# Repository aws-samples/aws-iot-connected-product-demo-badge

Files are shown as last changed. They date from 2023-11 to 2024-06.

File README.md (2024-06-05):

# AWS IoT - Connected Product - Demo Badge

## Workshop

The Demo Badge device was built for this hands-on workshop at re:Invent 2023 and future events:

https://catalog.workshops.aws/aws-iot-connected-product-demo-badge

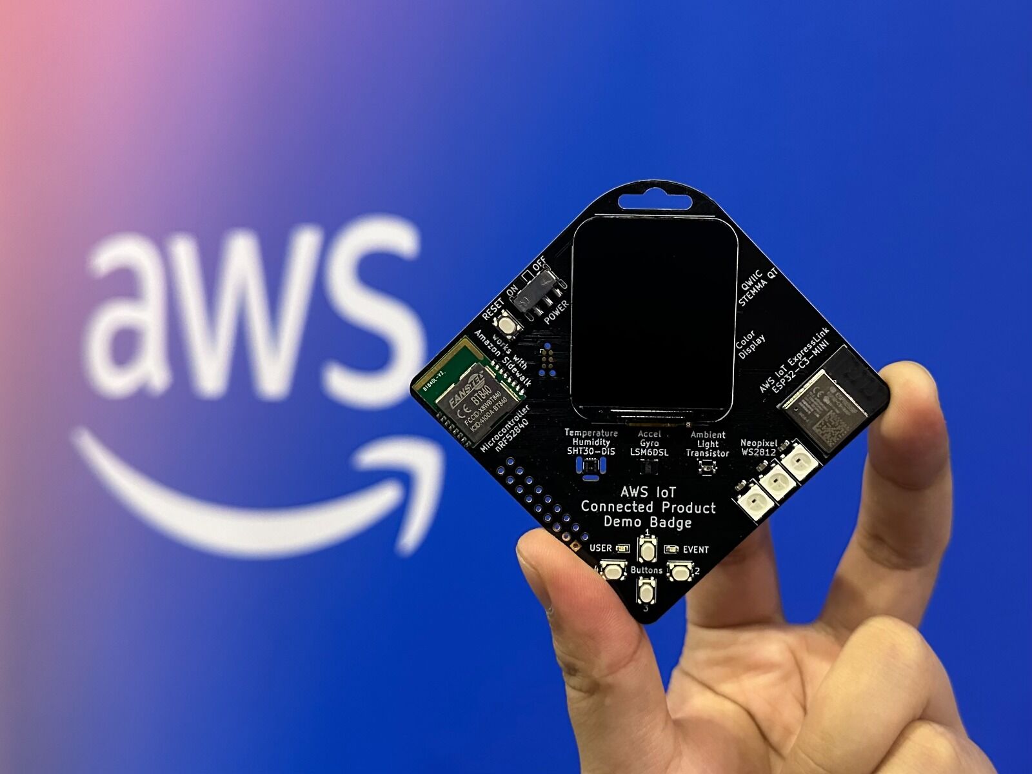
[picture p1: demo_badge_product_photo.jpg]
photo of the Demo Badge


Rendering of front and backside of the Demo Badge:
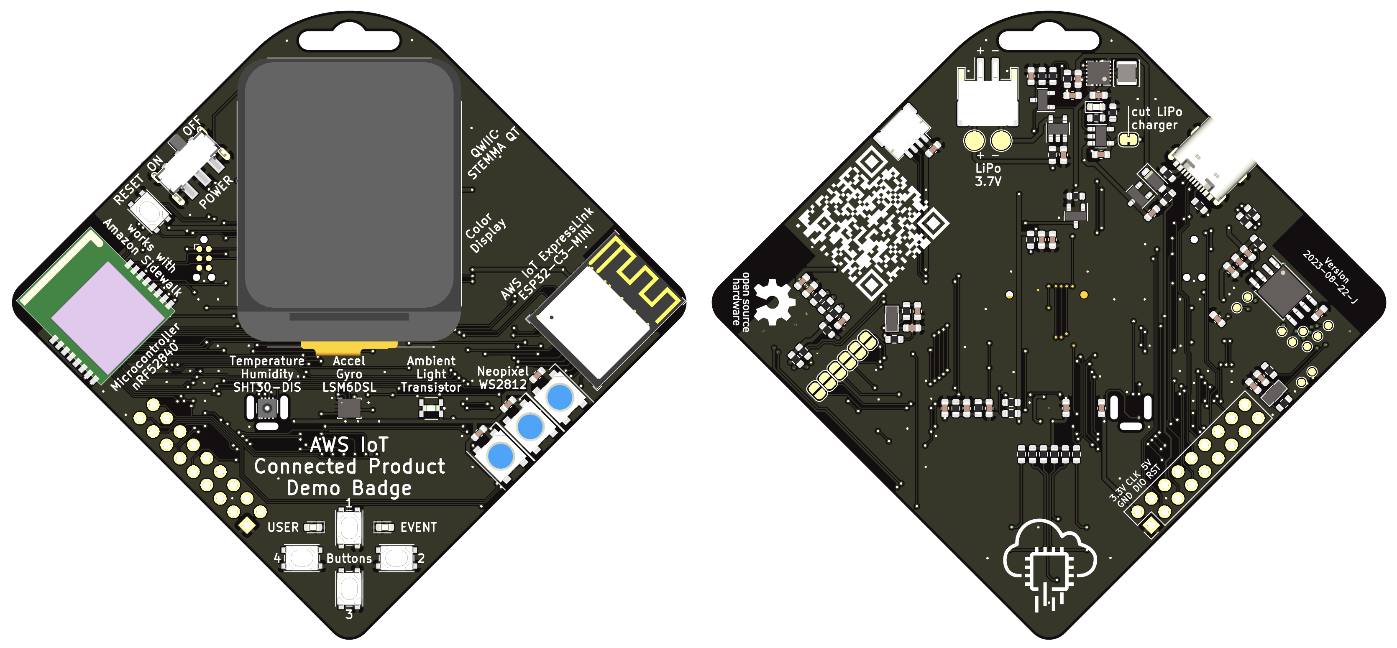
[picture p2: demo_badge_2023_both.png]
rendering of front and backside of Demo Badge


## Hardware

See the [Hardware README](./hardware/README.md) file.

### Where to buy?

Seeed Studio manufactured the devices for re:Invent 2023.

You can pre-order devices directly from the Seeed Studio online store [product listing for the Demo Badge](https://www.seeedstudio.com/AWS-IoT-Connected-Product-p-5844.html).

If you are interesting in customizing the Demo Badge for your own product design, please reach out to fusion@seeed.io directly, and tell them about the Demo Badge device!

## Firmware

See the [Firmware README](./firmware/README.md) file.

## Cloud Infrastructure with CDK

See the [CDK](./cloud-infrastructure/cdk/) folder.

## Security

See [CONTRIBUTING](CONTRIBUTING.md#security-issue-notifications) for more information.

## License

This project is licensed under the MIT-0 License, except files explicitly marked under different license. See the LICENSE file.

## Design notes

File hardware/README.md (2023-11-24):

# AWS IoT - Connected Product - Demo Badge 2023

This device was designed and created for a [hands-on workshop at re:Invent 2023](https://catalog.workshops.aws/aws-iot-connected-product-demo-badge).

The Demo Badge features an nRF52840 microcontroller, an Espressif ESP32-C3-MINI-1-A AWS IoT ExpressLink module, various sensors, buttons, RGB LEDs, and a color display.

## Schematic

The schematic for the Demo Badge is available as KiCAD 7 project. You can access a [PDF version of the schematic here](./snapshot/demo-badge-2023-schematic.pdf).

## PCB Layout

The PCB layout for the Demo Badge is available as KiCAD 7 project, including all footprints (publicly available ones, and custom ones).

You can access the [production Gerber files here](./snapshot/gerbers/).

## License

This hardware design is licensed under the MIT-0 License. Imported footprints and 3D models might contain different licenses.

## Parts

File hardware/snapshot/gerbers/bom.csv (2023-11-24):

LCSC Part # | Designator | Footprint | LCSC Part #
C146233 | A1 | ALS-PT19-315C_L177_TR8 | C146233
C107045 | C29,C34,C39,C40 | C_0603_1608Metric | C107045
C14663 | C1,C2,C3,C10,C14,C18,C20,C22,C41 | C_0603_1608Metric | C14663
C15849 | C4,C5,C6,C11,C15,C17,C21,C35 | C_0603_1608Metric | C15849
C19666 | C8,C30,C31,C36 | C_0603_1608Metric | C19666
C19702 | C7,C19,C28,C32,C33 | C_0603_1608Metric | C19702
C223608 | D7 | D_SOD-123F | C223608
C72043 | D4,D5,D6 | LED_0603_1608Metric | C72043
C2874885 | D1,D2,D3 | SK6812-multi | C2874885
C295747 | J7 | JST_PH_S2B-PH-SM4-TB_1x02-1MP_P2.00mm_Horizontal | C295747
C145956 | J3 | JST_SH_SM04B-SRSS-TB_1x04-1MP_P1.00mm_Horizontal | C145956
C2988369 | J2 | USB_C_Receptacle_Palconn_UTC16-G | C2988369
C167747 | L1 | L_Changjiang_FNR3015S | C167747
C8545 | Q1,Q3 | SOT-23 | C8545
C150470 | Q2 | SOT-23 | C150470
C2999459 | R6 | R_0603_1608Metric | C2999459
C25190 | R3,R4 | R_0603_1608Metric | C25190
C103204 | R16,R17,R34,R49 | R_0603_1608Metric | C103204
C21190 | R8,R33,R52 | R_0603_1608Metric | C21190
C3013567 | R22,R23,R29,R35,R36 | R_0603_1608Metric | C3013567
C25804 | R5,R7,R9,R10,R11,R12,R13,R14,R15,R18,R19,R20,R31,R37,R50 | R_0603_1608Metric | C25804
C103809 | R2 | R_0603_1608Metric | C103809
C163869 | R1 | R_0603_1608Metric | C163869
C221660 | SW8 | JS102011SAQN | C221660
C2689510 | SW1,SW2,SW3,SW4,SW5 | PTS815 | C2689510
C328560 | U12 | SOT-23-5 | C328560
C5182373 | U4 | Fanstel-BT840 | C5182373
C9900056240 | U13 | ER-TFT1.69-2 | C9900056240
C5224444 | U6 | ESP32-C3-MINI-1 | C5224444
C126672 | U5 | LGA-14_3x2.5mm_P0.5mm_LayoutBorder3x4y | C126672
C77361 | U1 | Sensirion_DFN-8-1EP_2.5x2.5mm_P0.5mm_EP1.1x1.7mm | C77361
C668215 | U10 | SOT-23-5 | C668215
C28060 | U9 | Texas_DRC0010J | C28060
C97521 | U14 | SOIC-8_5.23x5.23mm_P1.27mm | C97521
C3035215 | Y1,Y3 | Crystal_SMD_3215-2Pin_3.2x1.5mm | C3035215

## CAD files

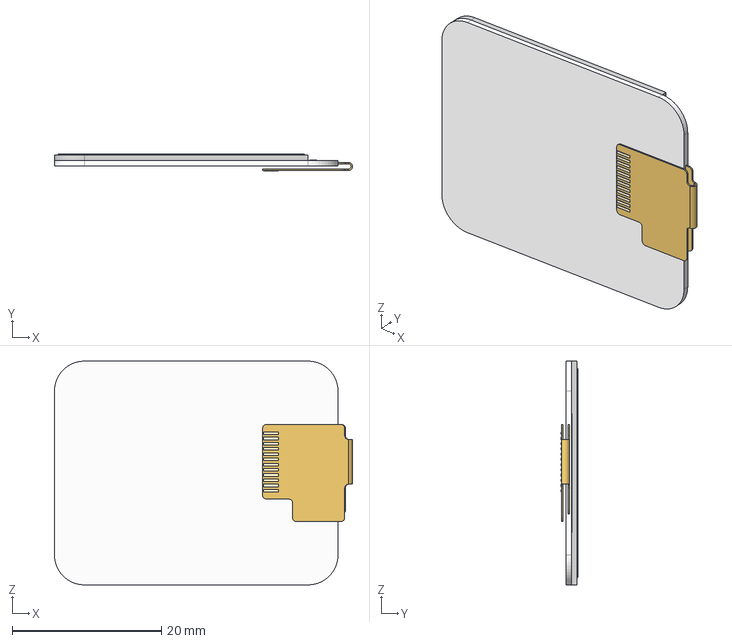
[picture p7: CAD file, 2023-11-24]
hardware/components/1.69” Round IPS.step
39.9 x 2.25 x 30.0 mm

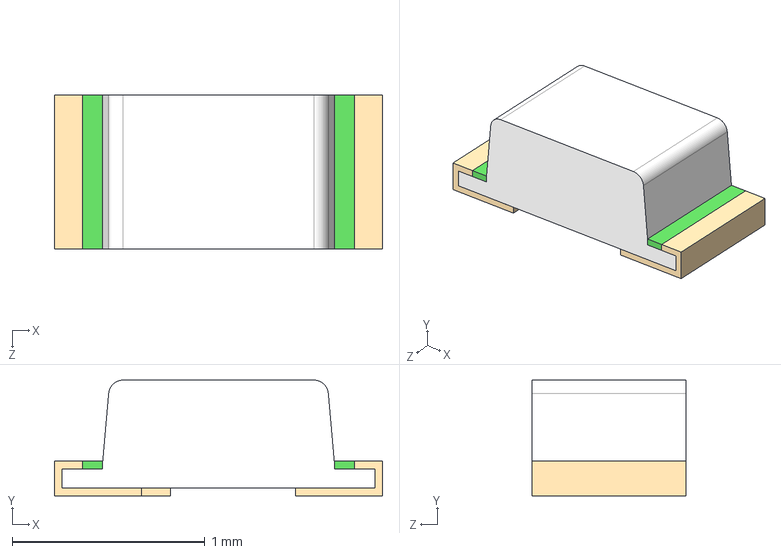
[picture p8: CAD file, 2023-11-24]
hardware/components/ALS-PT19-315C_L177_TR8/ALS-PT19-315C_L177_TR8.step
1.70 x 0.6 x 0.8 mm

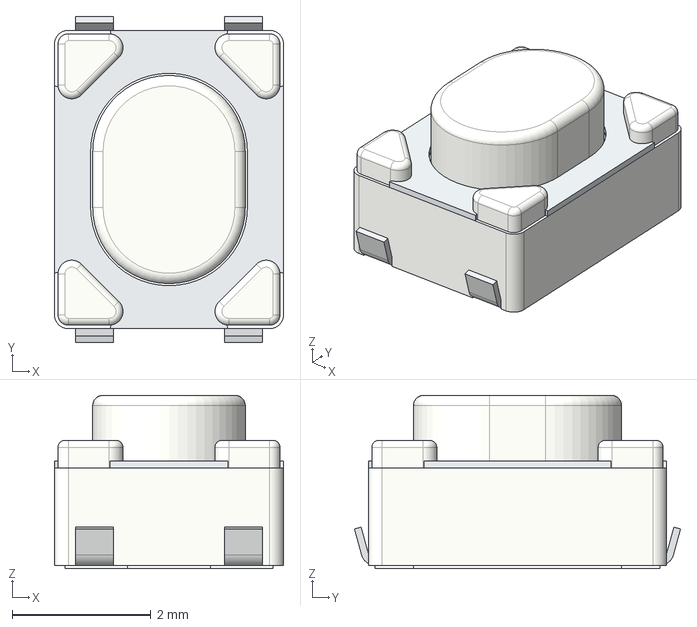
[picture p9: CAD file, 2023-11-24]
hardware/components/PTS815/PTS815.stp
3.30 x 4.70 x 2.50 mm

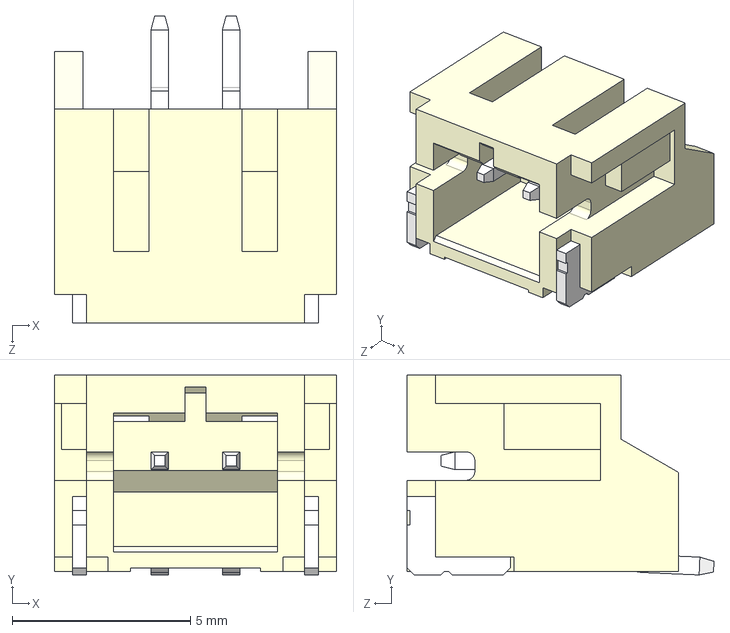
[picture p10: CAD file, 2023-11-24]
hardware/components/S2B-PH-SM4-TB(LF)(SN)--3DModel-STEP-56544.STEP
7.90 x 5.60 x 8.60 mm

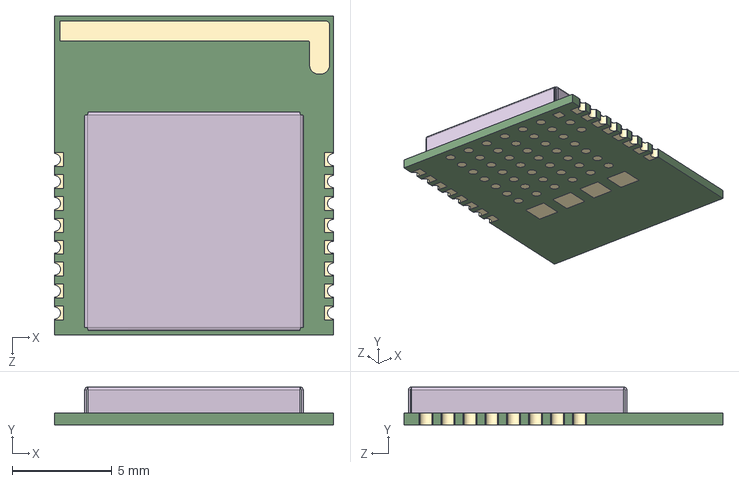
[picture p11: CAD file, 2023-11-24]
hardware/components/BT840.step
14.0 x 1.90 x 16.0 mm

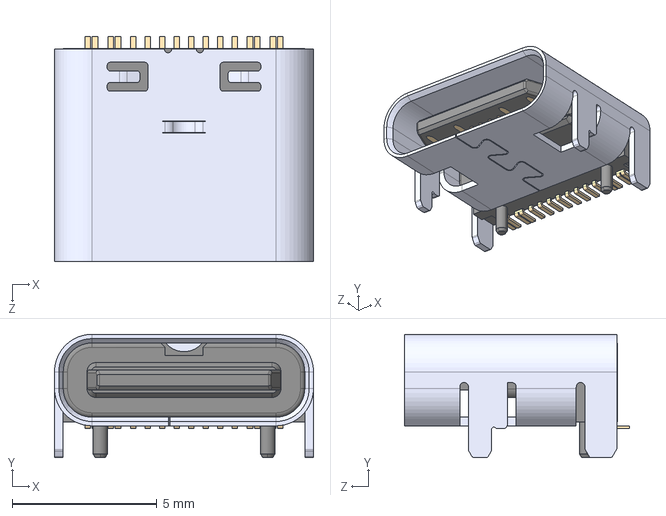
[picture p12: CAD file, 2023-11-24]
hardware/components/CSP-USC16-TR--3DModel-STEP-468060.STEP
8.94 x 4.26 x 7.75 mm

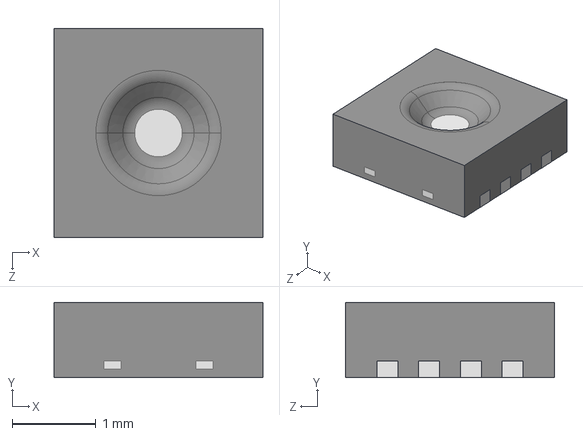
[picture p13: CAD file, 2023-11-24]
hardware/components/SHT30-DIS.STEP
2.50 x 0.901 x 2.50 mm

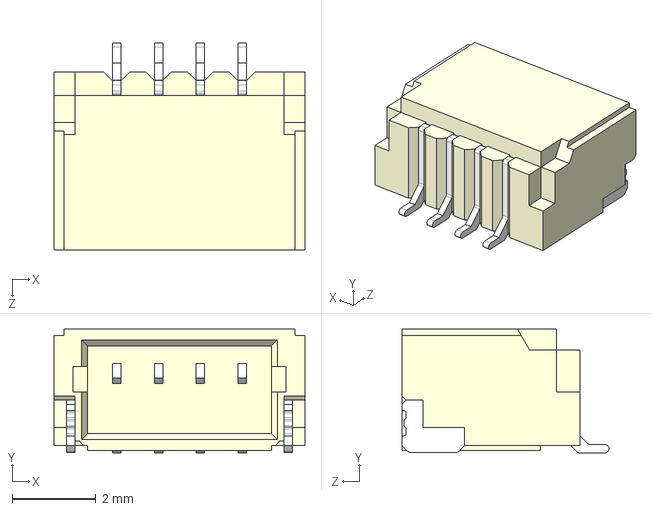
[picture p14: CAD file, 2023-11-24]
hardware/components/SM04B-SRSS-TB.STEP
6.00 x 2.96 x 4.95 mm

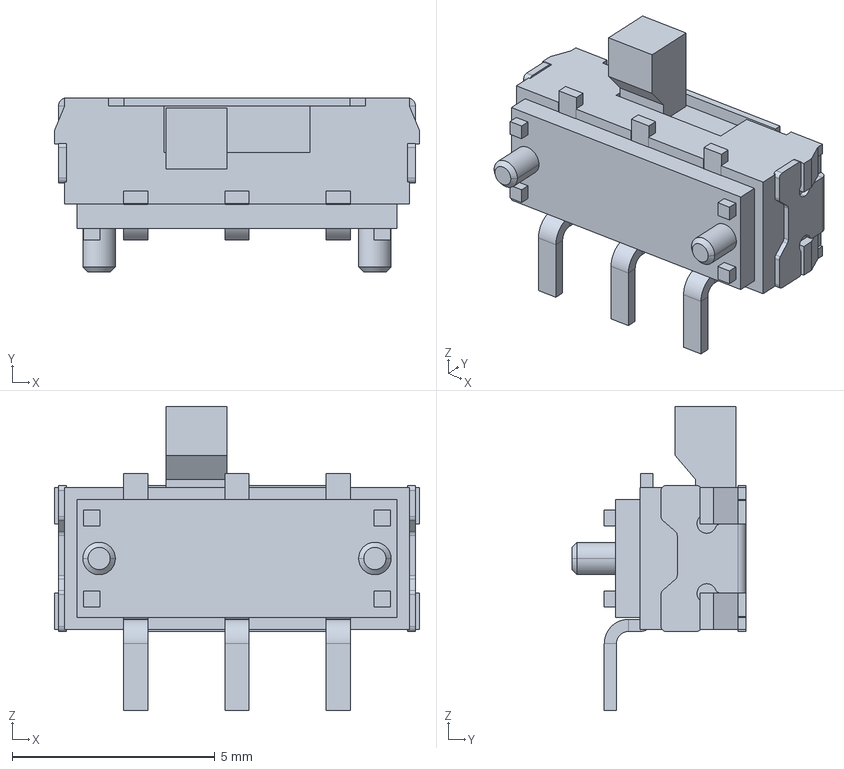
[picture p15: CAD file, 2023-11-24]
hardware/components/JS102011SAQN/JS102011SAQN.step
9.00 x 4.30 x 7.50 mm

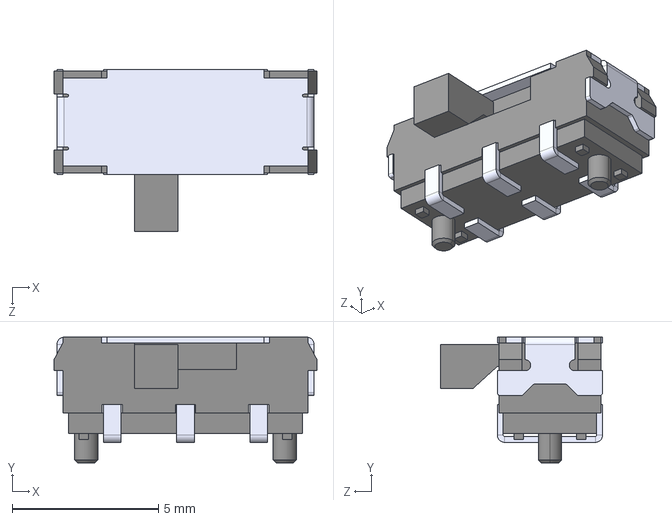
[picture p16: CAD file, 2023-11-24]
hardware/components/JS202011JAQN/JS202011JAQN.step
9.00 x 4.30 x 5.55 mm

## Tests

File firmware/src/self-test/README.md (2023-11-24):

# AWS IoT - Connected Product - Demo Badge 2023

This document will guide you through the steps to:
- flash the Demo Badge device with a self-test FW
- run the self-test FW to perform a functional test of the device

## Setup
- programming tool:
  - linux or windows machine
  - OpenOCD v0.12.0
  - a nrf52 programmer supported by OpenOCD
- the "demobadge-xxx.zip" archive
- device:
  - programmer connected to the programming port
  - USB-C cable connected to the port
  - POWER switch in the ON position

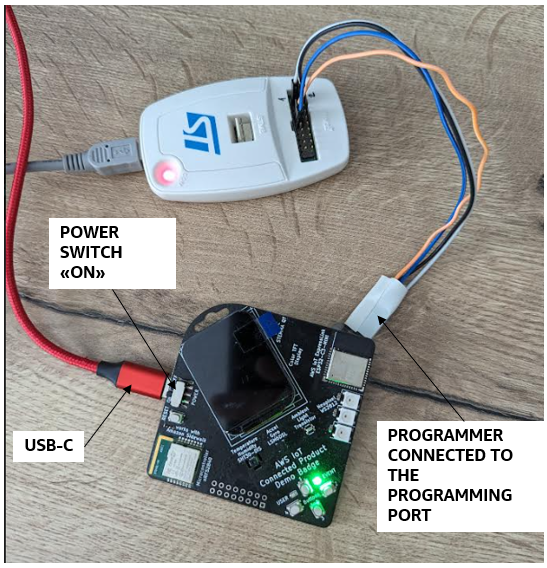
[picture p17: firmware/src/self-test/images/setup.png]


## STEP1. unzip the self-test FW package
Copy the demobadge-xxx.zip archive to the linux/windows machine and unzip it.

On a linux machine:

```bash
unzip demobadge-xxx.zip
```

Make sure the following files has been extracted to folder "./demobadge-xxx"
./flash.cfg
./build/self_test_firmware_20230922.hex

## STEP2. flash the self-test FW
Flash the "self_test_firmware_20230922.hex" to the device.

On a linux machine:

```bash
cd ./demobadge-xxx/
openocd -f flash.cfg
```

If the programming was successful, OpenOCD's output should look like:



## STEP3. run the tests
The device is now programmed with the self-test FW.

### TEST 1
- ACTION:
  - make sure the device is powered on through the USB-C cable
  - make sure the POWER SWITCH is in the ON position
- SUCCESS CRITERIA:
  - all LEDs are OFF
  - display shows "Press B1"
  - display and LEDs must look like this:

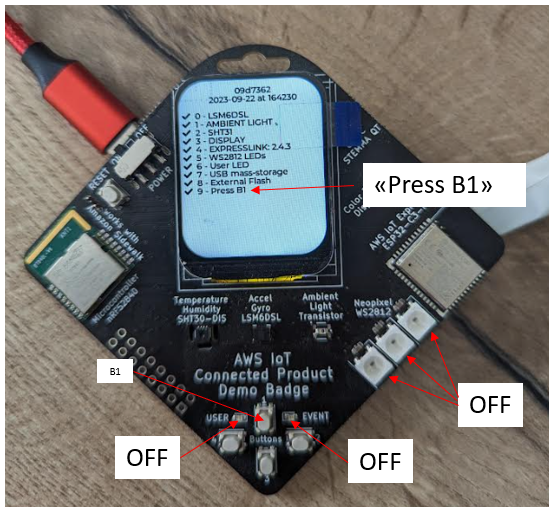
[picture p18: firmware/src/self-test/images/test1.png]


In case the LEDs or the display do not behave as described, press the RESET button and try TEST1 again.

If it does not work, power-cycle the device:
- move the POWER switch to the OFF position
- wait 1s
- move the POWER switch to the ON position
- try TEST1 again

If it fails, discard the device.
Otherwise move to next test.

### TEST 2
- ACTION:
  - do press user button 1
- SUCCESS CRITERIA:
  - strip LED 1 turns on to BLUE
  - display shows "Press B2"
  - display and LEDs must look like this:

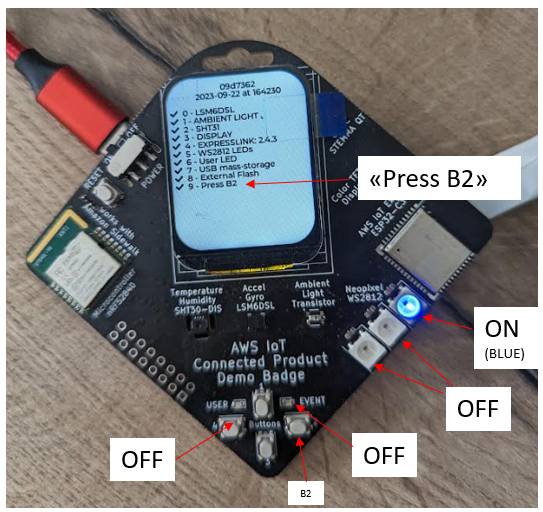
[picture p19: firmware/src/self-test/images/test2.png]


If it fails, discard the device.
Otherwise move to next test.

### TEST 3
- ACTION:
  - do press user button 2
- SUCCESS CRITERIA:
  - strip LED 1 and 2 turn on to BLUE
  - display shows "Press B3"
  - display and LEDs must look like this:

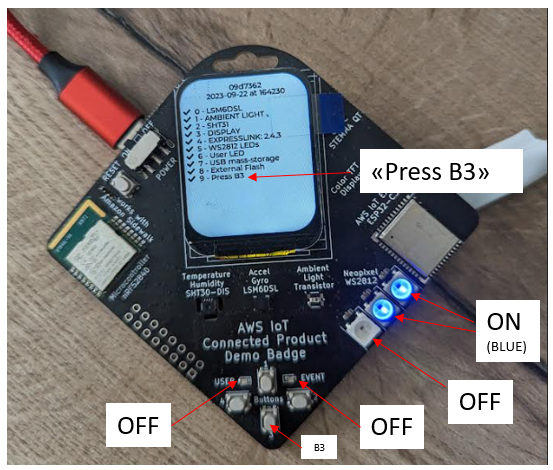
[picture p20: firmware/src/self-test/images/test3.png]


If it fails, discard the device.
Otherwise move to next test.

### TEST 4
- ACTION:
  - do press user button 3
- SUCCESS CRITERIA:
  - strip LED 1, 2, and 3 turn on to BLUE
  - display shows "Press B4"
  - display and LEDs must look like this:

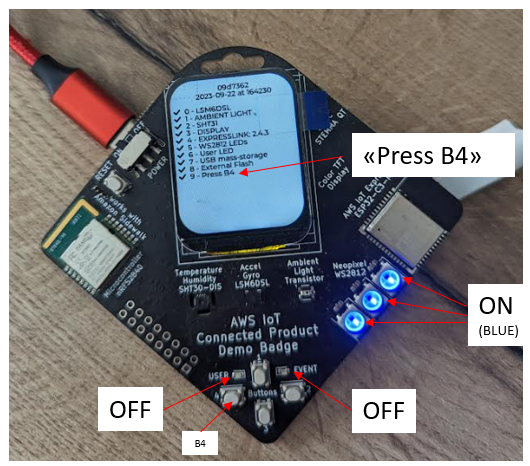
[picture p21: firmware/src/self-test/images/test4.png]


If it fails, discard the device.
Otherwise move to next test.

### TEST 5

- ACTION:
  - press user button 4
- SUCCESS CRITERIA:
  - display shows "PASSED"
  - ALL the LEDs (3xStrip, 1xUSER and 1xEVENT LEDs) are ON and GREEN
  - display and LEDs must look like this:

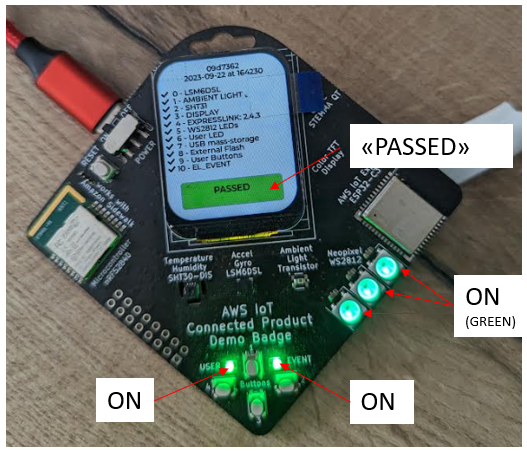
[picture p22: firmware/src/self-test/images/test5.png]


If it fails, discard the device.
Otherwise the self-test has PASSED.

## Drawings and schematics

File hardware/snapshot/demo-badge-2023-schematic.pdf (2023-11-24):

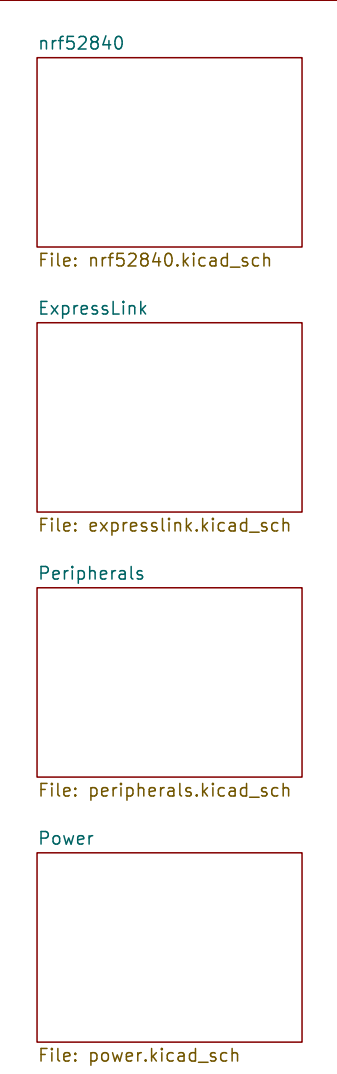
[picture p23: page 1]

nrf52840 File: nrf52840.kicad_sch Power File: power.kicad_sch

https://github.com/aws-samples/aws-iot-connected-product-demo-badge

Id: 1/5 Title: AWS IoT - Connected Product - Demo Badge 2023

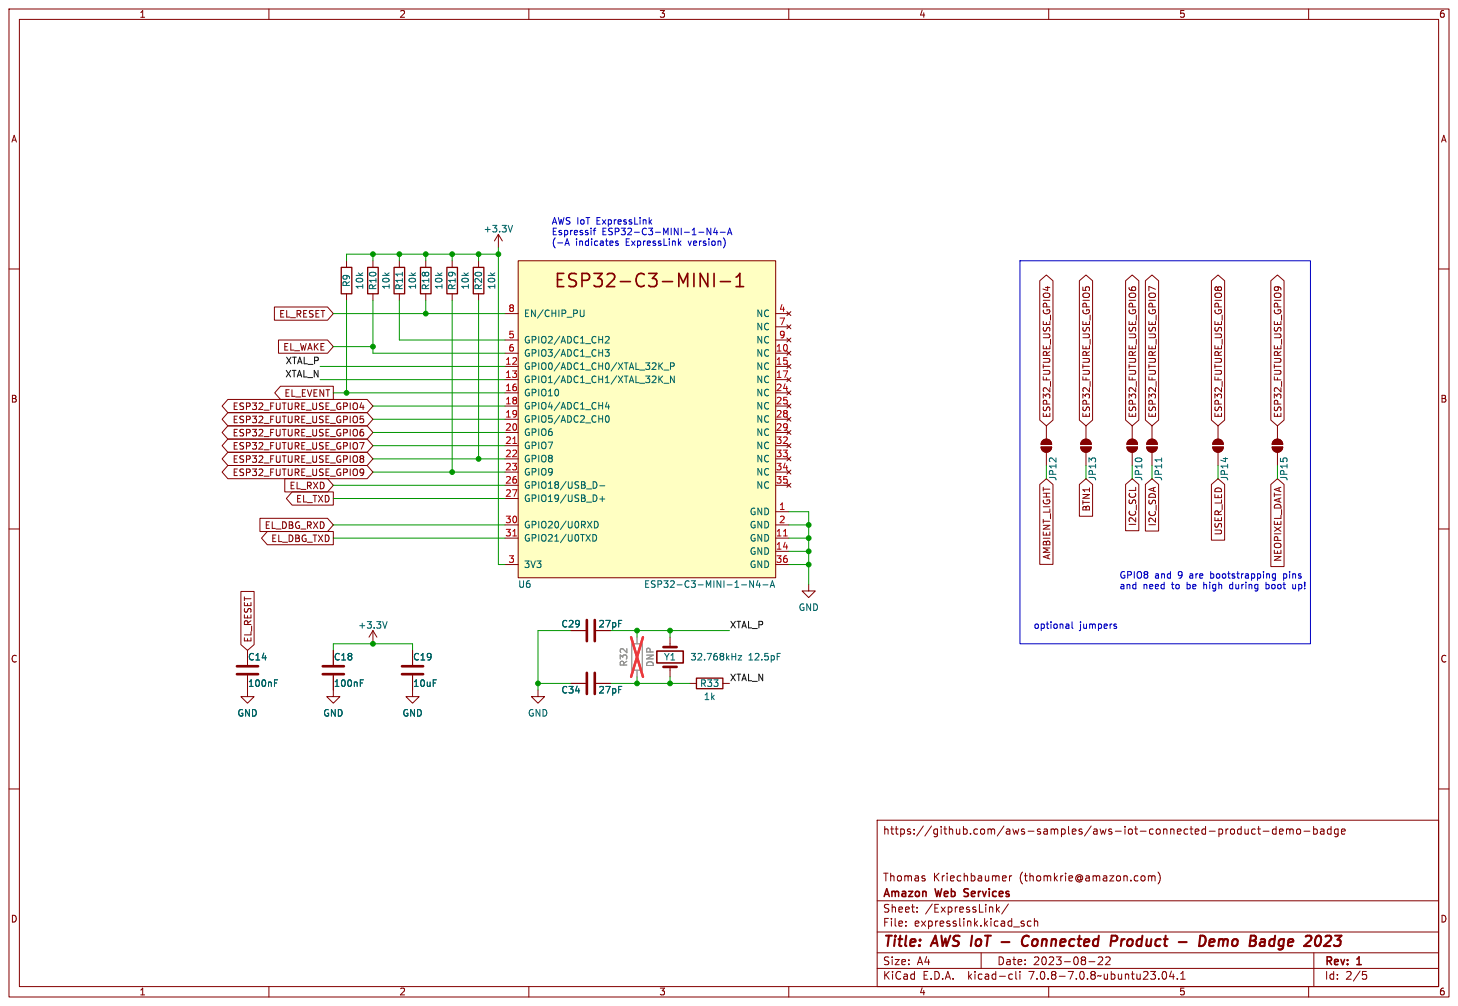
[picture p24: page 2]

XTAL_N
https://github.com/aws-samples/aws-iot-connected-product-demo-badge R33

Id: 2/5 Title: AWS IoT - Connected Product - Demo Badge 2023

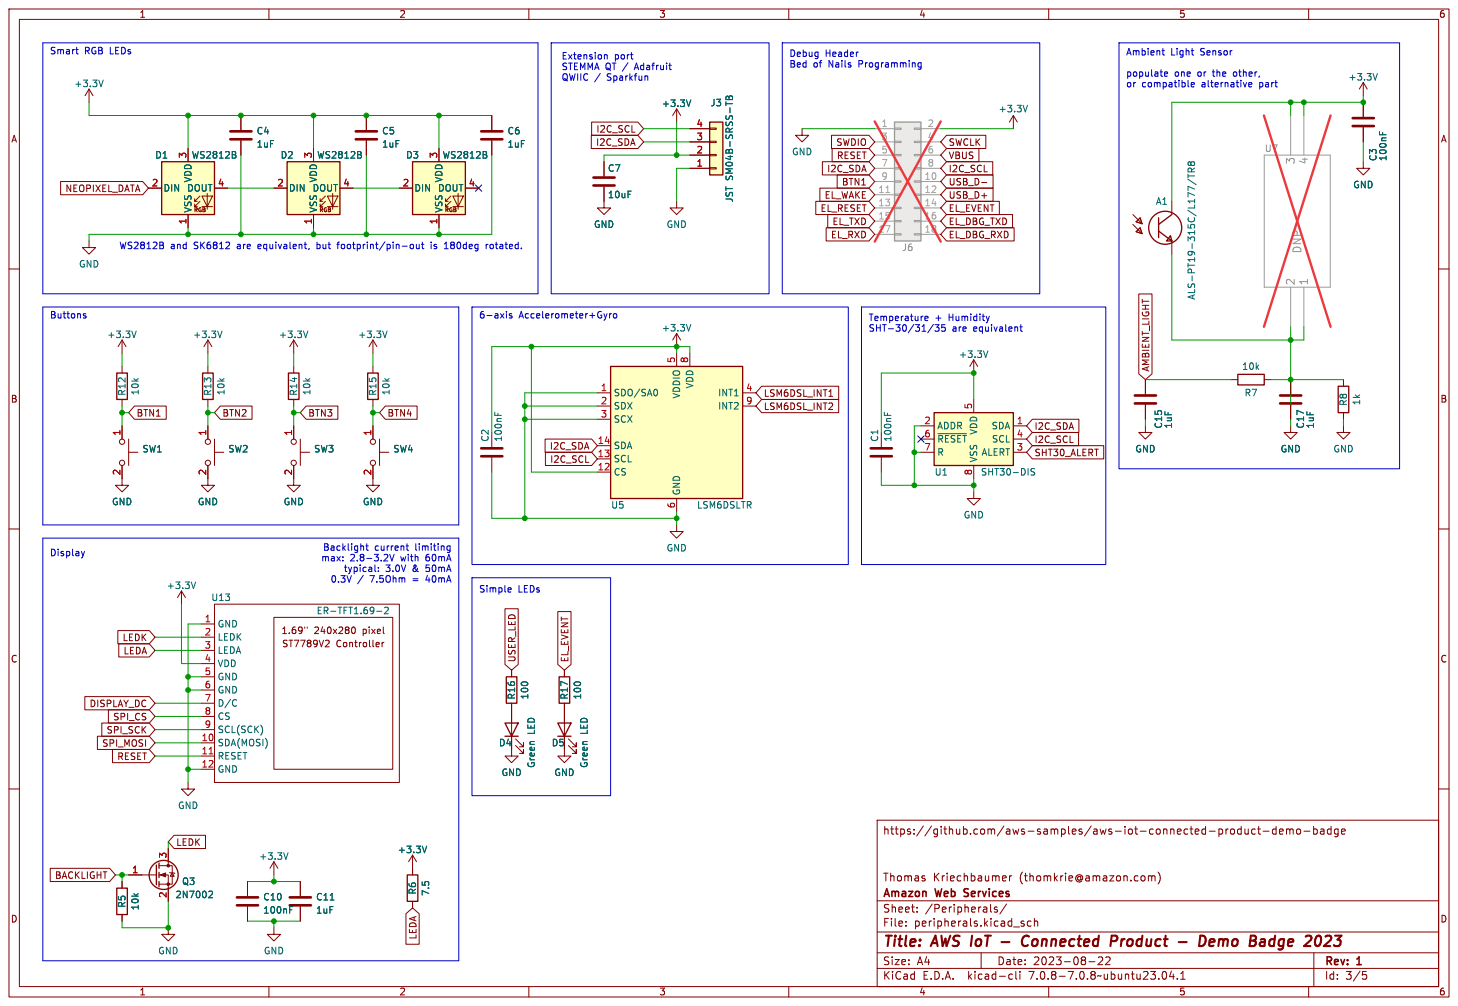
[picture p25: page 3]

3 DOUT 4 D3 WS2812B VSS RGB 1 DIN 2 VDD

Id: 3/5 Title: AWS IoT - Connected Product - Demo Badge 2023

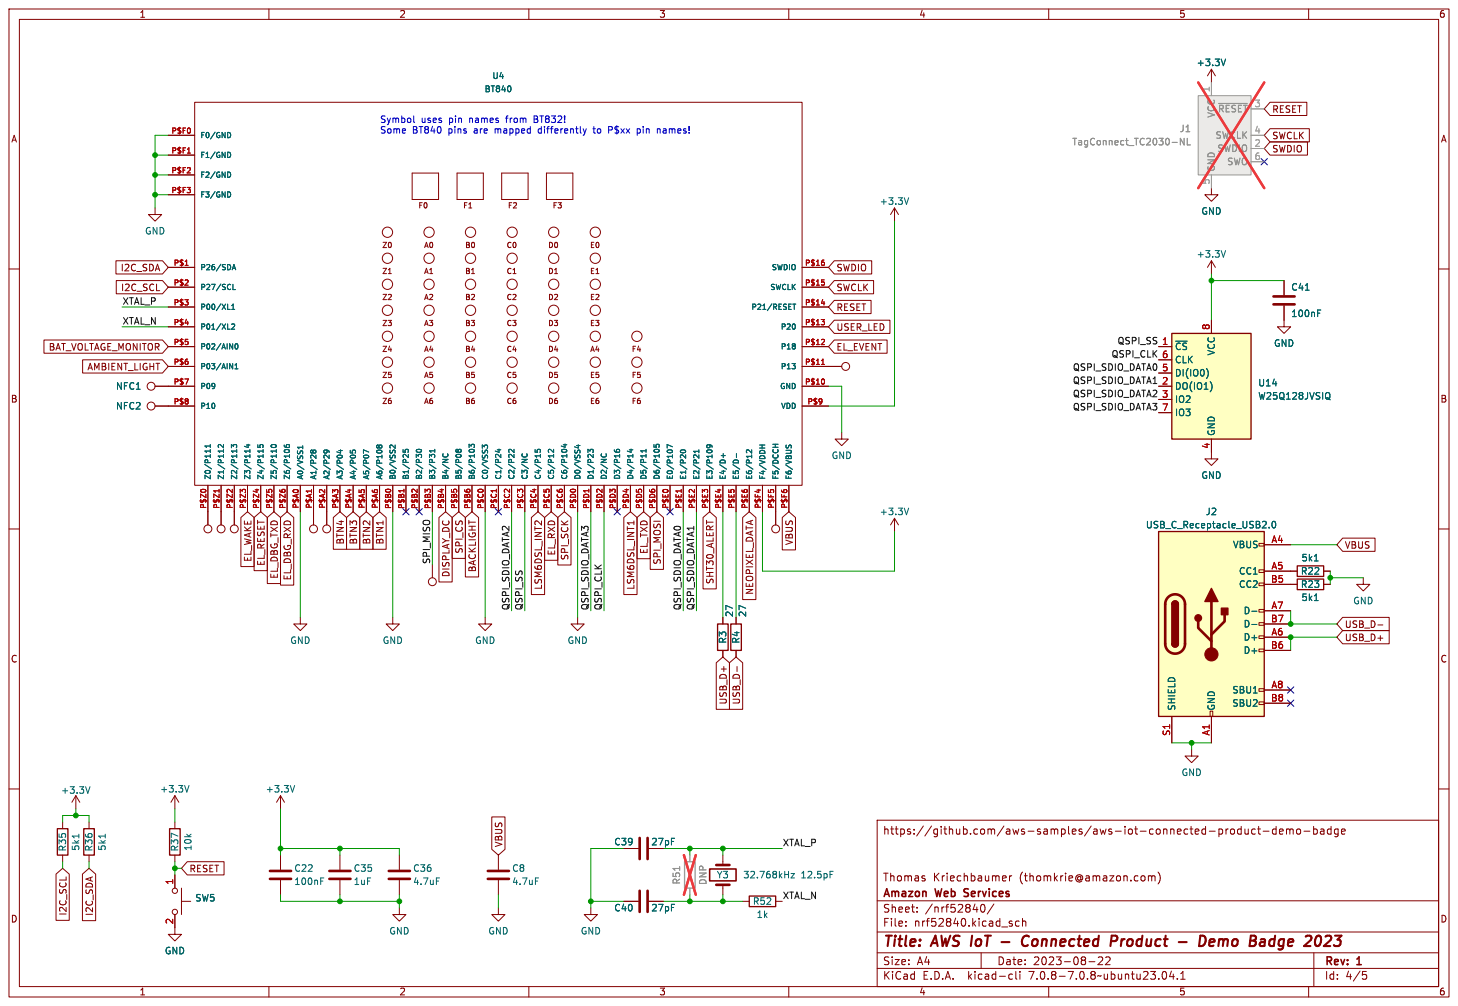
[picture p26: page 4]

1 SWDIO 2 ~{RESET}3 SWCLK 4 GND

Id: 4/5 Title: AWS IoT - Connected Product - Demo Badge 2023

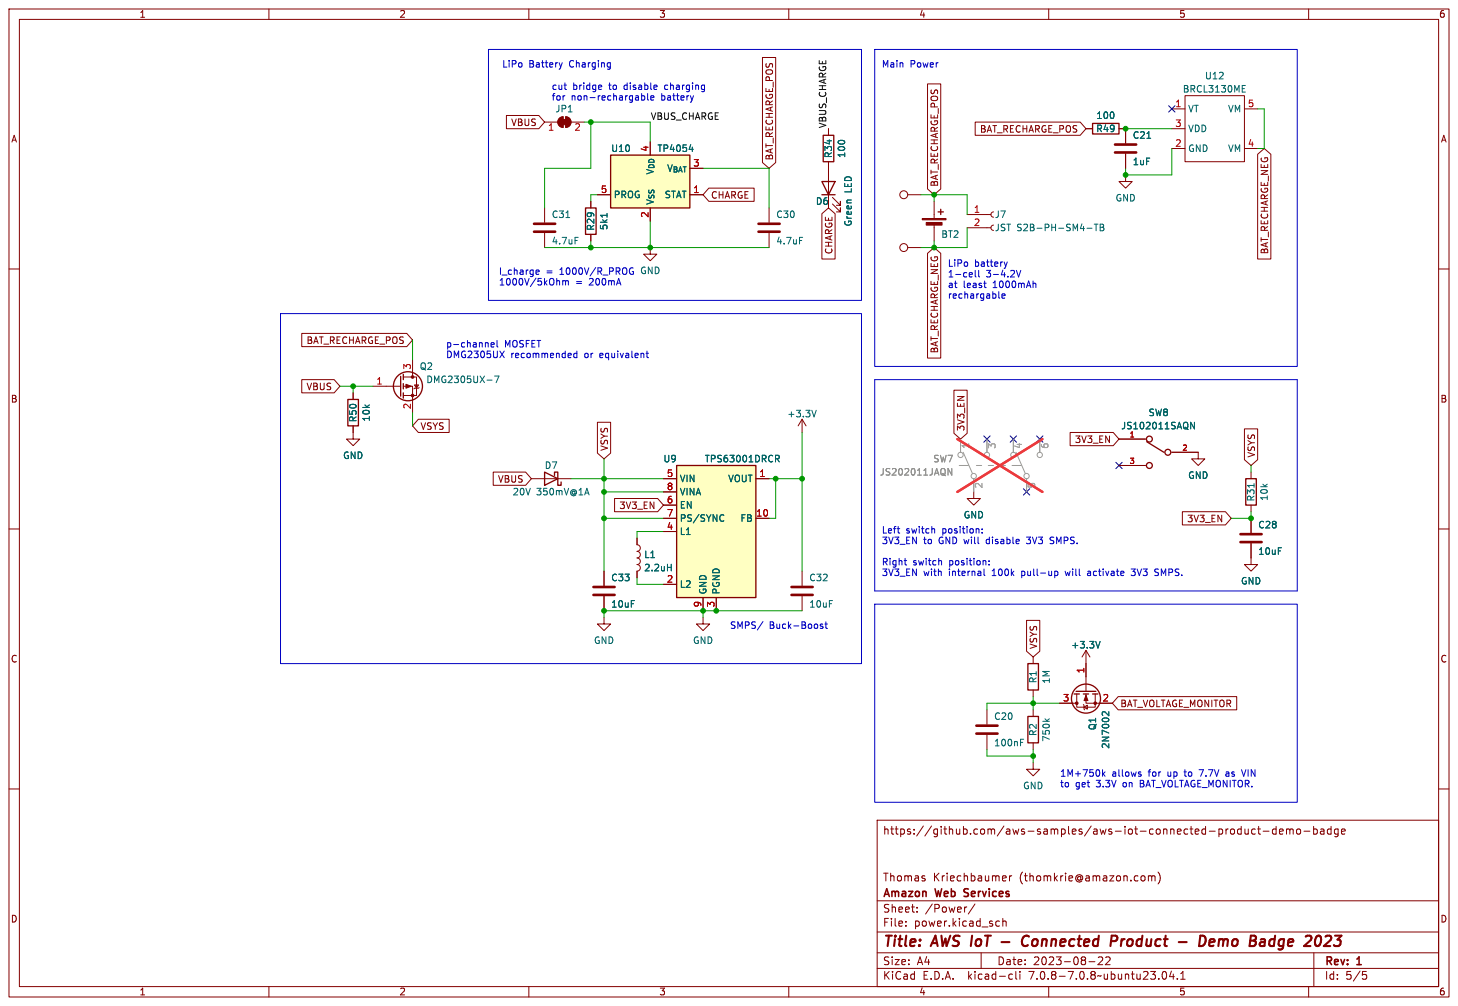
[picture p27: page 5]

Id: 5/5 Title: AWS IoT - Connected Product - Demo Badge 2023

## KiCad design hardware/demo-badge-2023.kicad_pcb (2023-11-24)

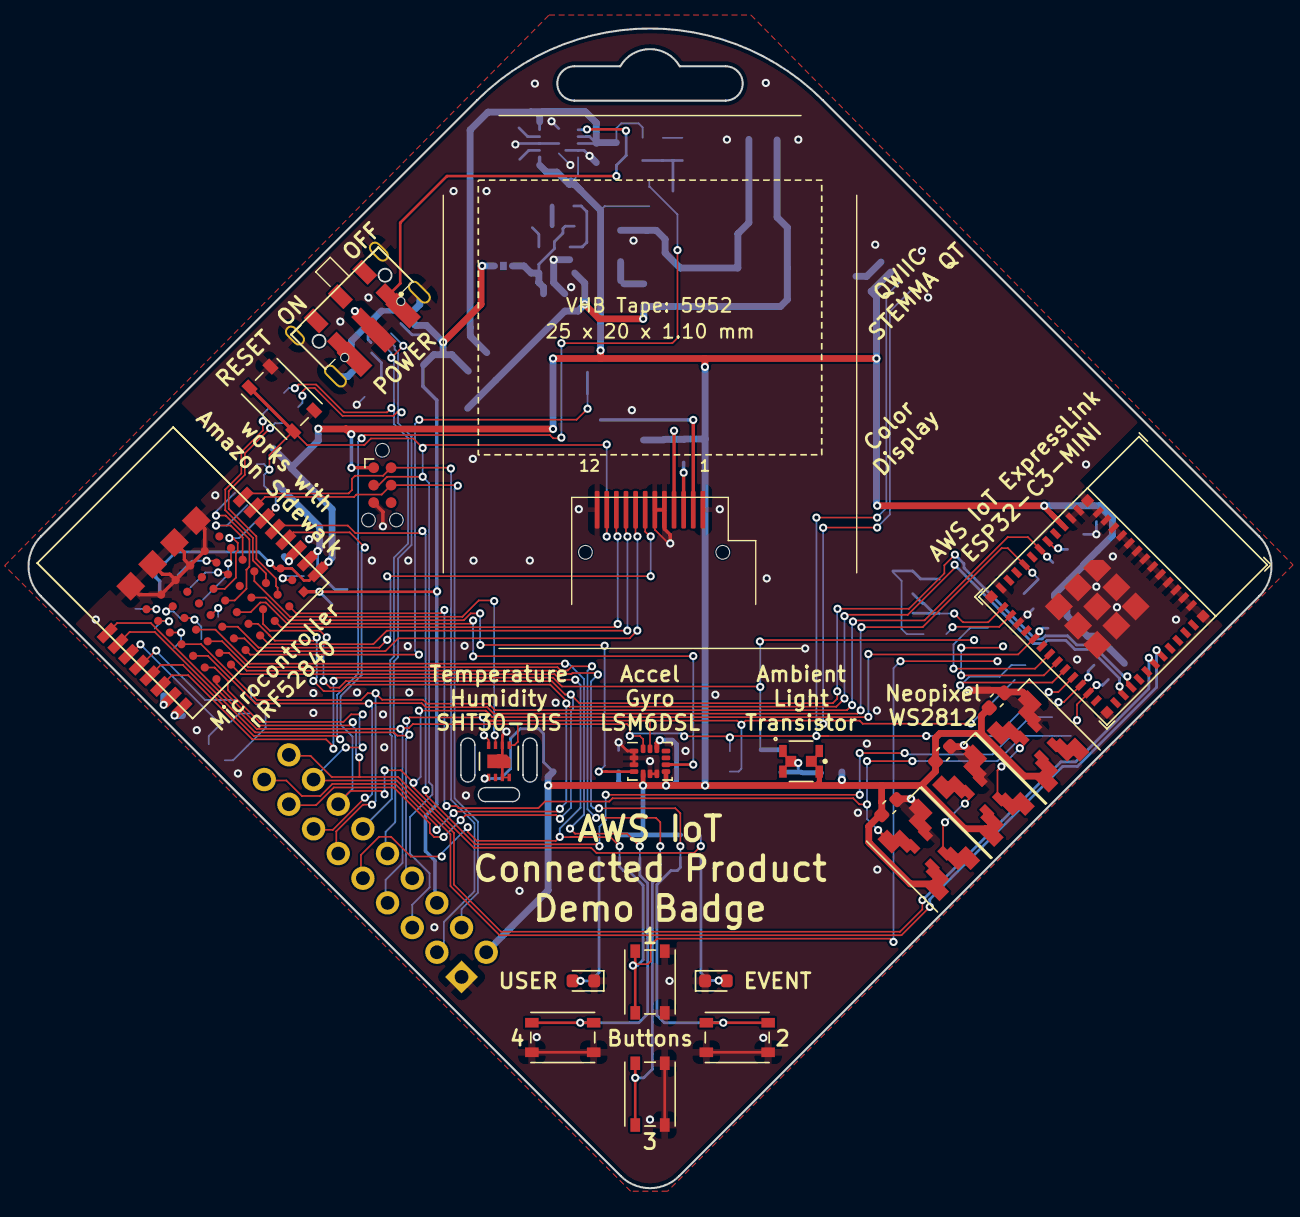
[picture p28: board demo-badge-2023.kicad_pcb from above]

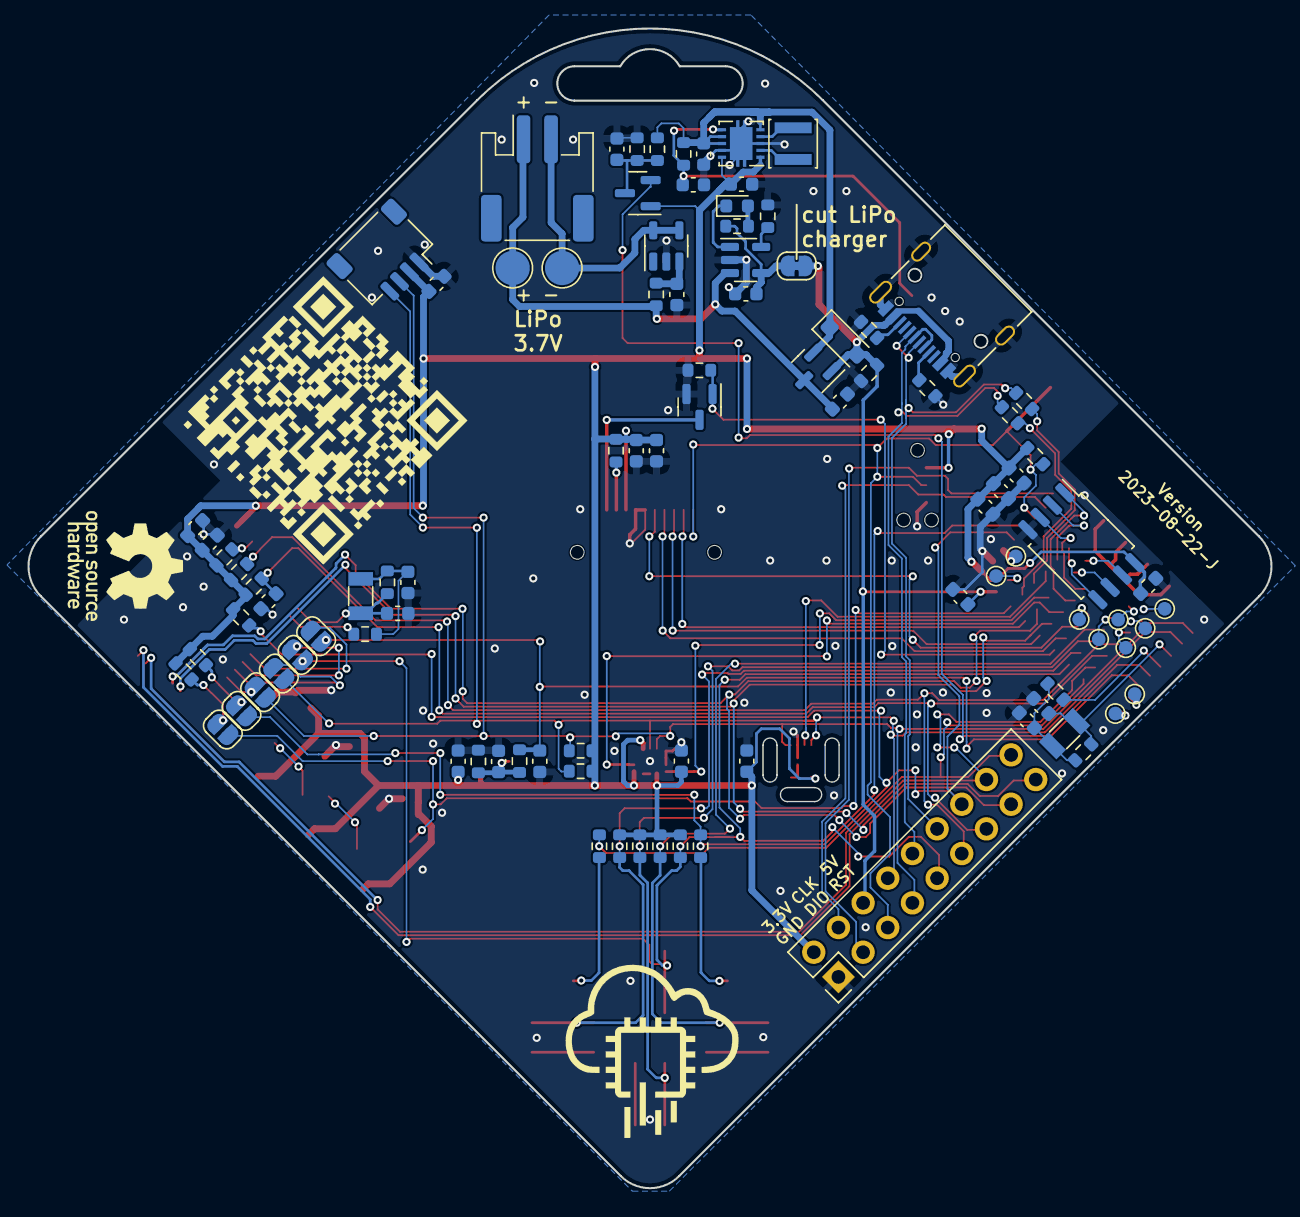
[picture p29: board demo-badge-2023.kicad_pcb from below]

Board: 2 copper layers, 90.5 x 84.4 mm, 119 parts (96 on the bottom side), 85 nets.

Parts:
A1: ALS-PT19-315C/L177/TR8; ALS-PT19-315C_L177_TR8
C1, C2, C3, C10, C14, C18, C20, C22, C41: 100nF; C_0603_1608Metric
C4, C5, C6, C11, C15, C17, C21, C35: 1uF; C_0603_1608Metric
C7, C19, C28, C32, C33: 10uF; C_0603_1608Metric
C8, C30, C31, C36: 4.7uF; C_0603_1608Metric
C29, C34, C39, C40: 27pF; C_0603_1608Metric
D1, D2, D3: WS2812B; SK6812-multi
D4, D5, D6: Green LED; LED_0603_1608Metric
D7: 20V 350mV@1A; D_SOD-123F
J1: TagConnect_TC2030-NL; Tag-Connect_TC2030-IDC-NL_2x03_P1.27mm_Vertical
J2: USB_C_Receptacle_USB2.0; USB_C_Receptacle_Palconn_UTC16-G
J3: JST SM04B-SRSS-TB; JST_SH_SM04B-SRSS-TB_1x04-1MP_P1.00mm_Horizontal
J6: DNP; PinHeader_2x09_P2.54mm_Vertical
J7: JST S2B-PH-SM4-TB; JST_PH_S2B-PH-SM4-TB_1x02-1MP_P2.00mm_Horizontal
JP1: SolderJumper_2_Bridged; SolderJumper-2_P1.3mm_Bridged_RoundedPad1.0x1.5mm
JP10, JP11, JP12, JP13, JP14, JP15: SolderJumper_2_Open; SolderJumper-2_P1.3mm_Open_RoundedPad1.0x1.5mm
L1: 2.2uH; L_Changjiang_FNR3015S
NFC1, NFC2: TestPoint; TestPoint_Pad_D1.0mm
Q1, Q3: 2N7002; SOT-23
Q2: DMG2305UX-7; SOT-23
R1: 1M; R_0603_1608Metric
R2: 750k; R_0603_1608Metric
R3, R4: 27; R_0603_1608Metric
R5, R7, R9, R10, R11, R12, R13, R14, R15, R18, R19, R20, R31, R37, R50: 10k; R_0603_1608Metric
R6: 7.5; R_0603_1608Metric
R8, R33, R52: 1k; R_0603_1608Metric
R16, R17, R34, R49: 100; R_0603_1608Metric
R22, R23, R29, R35, R36: 5k1; R_0603_1608Metric
R32, R51: DNP; R_0603_1608Metric
SW1, SW2, SW3, SW4, SW5: PTS815
SW7: JS202011JAQN
SW8: JS102011SAQN
TP1, TP2, TP3, TP4, TP5, TP8, TP9, TP11: TestPoint; TestPoint_Pad_D1.0mm
TP6, TP7: TestPoint; TestPoint_Pad_D2.5mm
U1: SHT30-DIS; Sensirion_DFN-8-1EP_2.5x2.5mm_P0.5mm_EP1.1x1.7mm
U4: BT840; Fanstel-BT840
U5: LSM6DSLTR; LGA-14_3x2.5mm_P0.5mm_LayoutBorder3x4y
U6: ESP32-C3-MINI-1-N4-A; ESP32-C3-MINI-1
U7: DNP; IN-S32GTLS
U9: TPS63001DRCR; Texas_DRC0010J
U10: TP4054; SOT-23-5
U12: BRCL3130ME; SOT-23-5
U13: ER-TFT1.69-2
U14: W25Q128JVSIQ; SOIC-8_5.23x5.23mm_P1.27mm
Y1, Y3: 32.768kHz 12.5pF; Crystal_SMD_3215-2Pin_3.2x1.5mm

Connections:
3V3_EN: C28.2, R31.2, SW7.1 (A), SW8.1, U9.6 (EN)
+3.3V: A1.1, C1.2, C2.2, C3.2, C4.2, C5.2, C6.2, C7.2, C10.2, C11.2, C18.2, C19.2, C22.2, C32.2, C35.2, C36.2, C41.2, D1.3 (VDD), D2.3 (VDD), D3.3 (VDD), J1.1 (VCC), J3.2, J6.2, Q1.1 (G), R6.2, R9.2, R10.2, R11.2, R12.2, R13.2, R14.2, R15.2, R18.2, R19.2, R20.2, R35.2, R36.2, R37.2, U1.5 (VDD), U4.P$9 (VDD), U4.P$F4 (F4/VDDH), U5.5 (VDDIO), U5.8 (VDD), U5.12 (CS), U6.3 (3V3), U7.3, U7.4, U9.1 (VOUT), U9.10 (FB), U13.4 (VDD), U14.8 (VCC)
/ExpressLink/XTAL_N: R33.2, U6.13 (GPIO1/ADC1_CH1/XTAL_32K_N)
/ExpressLink/XTAL_P: C29.1, R32.2, U6.12 (GPIO0/ADC1_CH0/XTAL_32K_P), Y1.2
/Power/VBUS_CHARGE: C31.2, JP1.2 (B), R34.2, U10.4 (V_{DD})
/nrf52840/QSPI_CLK: U4.P$D2 (D2/NC), U14.6 (CLK)
/nrf52840/QSPI_SDIO_DATA0: U4.P$E1 (E1/P20), U14.5 (DI(IO0))
/nrf52840/QSPI_SDIO_DATA1: U4.P$E2 (E2/P21), U14.2 (DO(IO1))
/nrf52840/QSPI_SDIO_DATA2: U4.P$C2 (C2/P22), U14.3 (IO2)
/nrf52840/QSPI_SDIO_DATA3: U4.P$D1 (D1/P23), U14.7 (IO3)
/nrf52840/QSPI_SS: U4.P$C3 (C3/NC), U14.1 (~CS)
/nrf52840/SPI_MISO: TP11.1, U4.P$B3 (B3/P31)
/nrf52840/XTAL_N: R52.2, U4.P$4 (P01/XL2)
/nrf52840/XTAL_P: C39.1, R51.2, U4.P$3 (P00/XL1), Y3.2
AMBIENT_LIGHT: C15.2, JP12.2 (B), R7.2, U4.P$6 (P03/AIN1)
BACKLIGHT: Q3.1 (G), R5.2, U4.P$B6 (B6/P103)
BAT_RECHARGE_NEG: J7.2, TP7.1, U12.4 (VM), U12.5 (VM)
BAT_RECHARGE_POS: C30.2, J7.1, Q2.3 (D), R49.1, TP6.1, U10.3 (V_{BAT})
BAT_VOLTAGE_MONITOR: Q1.2 (S), U4.P$5 (P02/AIN0)
BTN1: J6.9, JP13.2 (B), R12.1, SW1.1, U4.P$A6 (A6/P108)
BTN2: R13.1, SW2.1, U4.P$A5 (A5/P07)
BTN3: R14.1, SW3.1, U4.P$A4 (A4/P05)
BTN4: R15.1, SW4.1, U4.P$A3 (A3/P04)
CHARGE: D6.1 (K), U10.1 (STAT)
DISPLAY_DC: U4.P$B4 (B4/NC), U13.7 (D/C)
EL_DBG_RXD: J6.18, U4.P$Z6 (Z6/P106), U6.30 (GPIO20/U0RXD)
EL_DBG_TXD: J6.16, U4.P$Z5 (Z5/P110), U6.31 (GPIO21/U0TXD)
EL_EVENT: J6.14, R9.1, R17.2, U4.P$12 (P18), U6.16 (GPIO10)
EL_RESET: C14.1, J6.13, R18.1, U4.P$Z4 (Z4/P115), U6.8 (EN/CHIP_PU)
EL_RXD: J6.17, U4.P$C5 (C5/P12), U6.26 (GPIO18/USB_D-)
EL_TXD: J6.15, U4.P$D5 (D5/P11), U6.27 (GPIO19/USB_D+)
EL_WAKE: J6.11, R10.1, U4.P$Z3 (Z3/P114), U6.6 (GPIO3/ADC1_CH3)
ESP32_FUTURE_USE_GPIO4: JP12.1 (A), U6.18 (GPIO4/ADC1_CH4)
ESP32_FUTURE_USE_GPIO5: JP13.1 (A), U6.19 (GPIO5/ADC2_CH0)
ESP32_FUTURE_USE_GPIO6: JP10.1 (A), U6.20 (GPIO6)
ESP32_FUTURE_USE_GPIO7: JP11.1 (A), U6.21 (GPIO7)
ESP32_FUTURE_USE_GPIO8: JP14.1 (A), R20.1, U6.22 (GPIO8)
ESP32_FUTURE_USE_GPIO9: JP15.1 (A), R19.1, U6.23 (GPIO9)
GND: C1.1, C2.1, C3.1, C4.1, C5.1, C6.1, C7.1, C8.1, C10.1, C11.1, C14.2, C15.1, C17.1, C18.1, C19.1, C20.1, C21.1, C22.1, C28.1, C29.2, C30.1, C31.1, C32.1, C33.1, C34.2, C35.1, C36.1, C39.2, C40.2, C41.1, D1.1 (VSS), D2.1 (VSS), D3.1 (VSS), D4.1 (K), D5.1 (K), J1.5 (GND), J2.A1 (GND), J2.A12 (GND), J2.B1 (GND), J2.B12 (GND), J2.S1 (SHIELD), J3.1, J6.1, Q3.2 (S), R2.2, R5.1, R8.1, R22.1, R23.1, R29.2, R50.2, SW1.2, SW2.2, SW3.2, SW4.2, SW5.2, SW7.2 (B), SW8.2, U1.2 (ADDR), U1.7 (R), U1.8 (VSS), U1.9 (VSS), U4.P$10 (GND), U4.P$A0 (A0/VSS1), U4.P$B0 (B0/VSS2), U4.P$C0 (C0/VSS3), U4.P$D0 (D0/VSS4), U4.P$F0 (F0/GND), U4.P$F1 (F1/GND), U4.P$F2 (F2/GND), U4.P$F3 (F3/GND), U5.1 (SDO/SA0), U5.2 (SDX), U5.3 (SCX), U5.6 (GND), U5.7 (GND), U6.1 (GND), U6.2 (GND), U6.11 (GND), U6.14 (GND), U6.36 (GND), U9.3 (PGND), U9.9 (GND), U9.11 (PGND), U10.2 (V_{SS}), U12.2 (GND), U13.1 (GND), U13.5 (GND), U13.6 (GND), U13.12 (GND), U14.4 (GND)
I2C_SCL: J3.4, J6.8, JP10.2 (B), R35.1, U1.4 (SCL), U4.P$2 (P27/SCL), U5.13 (SCL)
I2C_SDA: J3.3, J6.7, JP11.2 (B), R36.1, U1.1 (SDA), U4.P$1 (P26/SDA), U5.14 (SDA)
LEDA: R6.1, U13.3 (LEDA)
LEDK: Q3.3 (D), U13.2 (LEDK)
LSM6DSL_INT1: U4.P$D4 (D4/P14), U5.4 (INT1)
LSM6DSL_INT2: U4.P$C4 (C4/P15), U5.9 (INT2)
NEOPIXEL_DATA: D1.2 (DIN), JP15.2 (B), U4.P$E6 (E6/P12)
unnamed: A1.2, C17.2, R7.1, R8.2, U7.1, U7.2
unnamed: C34.1, R32.1, R33.1, Y1.1
unnamed: C40.1, R51.1, R52.1, Y3.1
unnamed: D1.4 (DOUT), D2.2 (DIN)
unnamed: D2.4 (DOUT), D3.2 (DIN)
unnamed: D4.2 (A), R16.1
unnamed: D5.2 (A), R17.1
unnamed: D6.2 (A), R34.1
unnamed: J2.A5 (CC1), R22.2
unnamed: J2.B5 (CC2), R23.2
unnamed: C20.2, Q1.3 (D), R1.2, R2.1
unnamed: TP8.1, U4.P$A1 (A1/P28)
unnamed: TP9.1, U4.P$A2 (A2/P29)
unnamed: R3.2, U4.P$E4 (E4/D+)
unnamed: R4.2, U4.P$E5 (E5/D-)
unnamed: TP2.1, U4.P$F5 (F5/DCCH)
unnamed: NFC1.1, U4.P$7 (P09)
unnamed: NFC2.1, U4.P$8 (P10)
unnamed: TP1.1, U4.P$11 (P13)
unnamed: TP3.1, U4.P$Z0 (Z0/P111)
unnamed: TP4.1, U4.P$Z1 (Z1/P112)
unnamed: TP5.1, U4.P$Z2 (Z2/P113)
unnamed: R11.1, U6.5 (GPIO2/ADC1_CH2)
unnamed: L1.1, U9.4 (L1)
unnamed: L1.2, U9.2 (L2)
unnamed: R29.1, U10.5 (PROG)
unnamed: C21.2, R49.2, U12.3 (VDD)
RESET: J1.3 (~RESET), J6.5, R37.1, SW5.1, U4.P$14 (P21/RESET), U13.11 (RESET)
SHT30_ALERT: U1.3 (ALERT), U4.P$E3 (E3/P109)
SPI_CS: U4.P$B5 (B5/P08), U13.8 (CS)
SPI_MOSI: U4.P$D6 (D6/P105), U13.10 (SDA(MOSI))
SPI_SCK: U4.P$C6 (C6/P104), U13.9 (SCL(SCK))
SWCLK: J1.4 (SWCLK), J6.4, U4.P$15 (SWCLK)
SWDIO: J1.2 (SWDIO), J6.3, U4.P$16 (SWDIO)
USB_D+: J2.A6 (D+), J2.B6 (D+), J6.12, R3.1
USB_D-: J2.A7 (D-), J2.B7 (D-), J6.10, R4.1
USER_LED: JP14.2 (B), R16.2, U4.P$13 (P20)
VBUS: C8.2, D7.2 (A), J2.A4 (VBUS), J2.A9 (VBUS), J2.B4 (VBUS), J2.B9 (VBUS), J6.6, JP1.1 (A), Q2.1 (G), R50.1, U4.P$F6 (F6/VBUS)
VSYS: C33.2, D7.1 (K), Q2.2 (S), R1.1, R31.1, U9.5 (VIN), U9.7 (PS/SYNC), U9.8 (VINA)

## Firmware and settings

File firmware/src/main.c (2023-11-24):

// Copyright Amazon.com, Inc. or its affiliates. All Rights Reserved.
// SPDX-License-Identifier: MIT-0

#define NRF_LOG_ENABLED 1
#define NRF_LOG_BACKEND_UART_ENABLED 1
#define NRF_LOG_BACKEND_SERIAL_USES_RTT 0

#include <time.h>

#include <zephyr/kernel.h>
#include <zephyr/logging/log.h>
LOG_MODULE_REGISTER(main);

#include "badge.h"

init_retcode_t init_retcode;

int main(void) {
    init_retcode.primary_thread = init_primary_thread();
    init_retcode.user_led = init_user_led();
    init_retcode.led_strip = init_led_strip();
    init_retcode.buttons = init_buttons();
    init_retcode.ambient_light = init_ambient_light();
    init_retcode.sht31 = init_sht31();
    init_retcode.lsm6dsl = init_lsm6dsl();
    init_retcode.expresslink = init_expresslink();
    init_retcode.display = init_display();
    init_retcode.usb_mass_storage = init_usb_mass_storage();

    k_msleep(1000);
    restore_active_workshop_module();

    return 0;
}

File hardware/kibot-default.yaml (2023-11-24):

kibot:
  version: 1

global:
  units: millimeters
  filters:
    - number: 1007
    - number: 1015
    - number: 58
  kiauto_time_out_scale: 10
  kiauto_wait_start: 900
  dir: generated

outputs:
  - name: basic_pdf_sch_print
    comment: Schematic in PDF format
    type: pdf_sch_print
    dir: +/schematic

  - name: step_3d_model
    comment: 3D model in STEP format
    type: step
    dir: +/3D

  - name: render_3d_top
    comment: 3D view from top
    type: render_3d
    dir: +/3D
    options:
      zoom: 3
      height: 1000
      width: 1000
      solder_mask: '#101010'
      background1: '#ffffff'
      background2: '#ffffff'
      # ray_tracing: true
      # orthographic: true
  - name: render_3d_bottom
    comment: 3D view from bottom
    type: render_3d
    dir: +/3D
    options:
      zoom: 3
      height: 1000
      width: 1000
      solder_mask: '#101010'
      background1: '#ffffff'
      background2: '#ffffff'
      # ray_tracing: true
      # orthographic: true
      view: bottom

  - name: FusionPCB_bom
    comment: BOM for FusionPCB
    type: bom
    dir: +/FusionPCB
    options:
      # http://support.seeedstudio.com/knowledgebase/articles/1886734-how-do-i-prepare-the-bill-of-materials-bom-file
      output: 'bom.%x'
      number: 9 # keep up-to-date with panelize rows/cols attributes
      # exclude_filter: only_jlc_parts
      group_fields:
        - Value
        - Footprint
        - "LCSC Part #"
      ref_separator: ','
      columns:
        - name: Designator
          field: References
        - name: MPN
          field: "LCSC Part #"
        - name: "Qty"
          field: "Build Quantity"
        - name: Link
          field: Datasheet
        - name: Footprint
          field: Footprint
        - name: "Quantity Per PCB"
          field: "Quantity Per PCB"
      csv:
        # hide_pcb_info: true
        # hide_stats_info: true
        quote_all: true

  - name: Panelizing with KiKit
    comment: auto-panelizing for multiple boards at once
    type: panelize
    dir: +/panel
    options:
      title: '+ (Panel)'
      units: mm
      default_angles: deg
      configs:
      - layout:
          # Max board size is limited by v-cut capabilities:
          # JLCPCB v-cut max panel dimensions: 300x300mm - https://jlcpcb.com/help/article/96-PCB-Panelization
          # JLCPCB Standard PCB Assembly max panel dimensions: 250x250mm - https://jlcpcb.com/help/article/96-PCB-Panelization
          # FusionPCB v-cut max panel dimensions: 380x380mm - http://support.seeedstudio.com/knowledgebase/articles/388503-what-are-the-pcb-panelization-rules
          # One DemoBadge with tabs and boarder is around 75x75mm
          rows: 3 # keep up-to-date with BOM `number` attribute
          cols: 3 # keep up-to-date with BOM `number` attribute
          rotation: "45deg"
          space: 3
        source:
          tolerance: 100
        tabs:
          type: fixed
          vwidth: 15
          hwidth: 15
        cuts:
          type: vcuts
          cutcurves: true
        framing:
          # type: frame
          type: tightframe
          fillet: 2
          slotwidth: 2
        tooling:
          type: "4hole"
          size: 1.152
          hoffset: 3
          voffset: 3
        fiducials:
          type: "4fid"
          hoffset: 3
          voffset: 6
          coppersize: 2
          opening: 1
        text:
          type: simple
          text: "{date}"
          hoffset: 5
          voffset: 3
        text2:
          type: simple
          text: "JLCJLCJLCJLC"
          hoffset: 25
          voffset: 3
        page:
          type: A0
        post:
          copperfill: true
          millradius: 1 # radius --- 2mm diameter cutter
          reconstructarcs: true
          # refillzones: true # seems to break the lanyard cut-out copper area
          # dimensions: true

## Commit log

2023-11-24 This is where it all begins...
    [1.69” Round IPS.step, ALS-PT19-315C_L177_TR8.step, BT840.step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]
2024-01-31 flashing instructions++
    [flash.cfg]
2024-01-31 display: wrap async lvgl handler to different thread
2024-01-31 self-test: expresslink EL_EVENT reset fix
    [expresslink.c]
2026-04-22 build(deps): bump uuid, @aws-sdk/client-iot, @aws-sdk/client-iot-data-plane, @aws-sdk/client-iot-wireless, @aws-sdk/client-lambda, @aws-sdk/client-s3, @aws-sdk/credential-provider-cognito-identity an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
    Bumps [uuid](https://github.com/uuidjs/uuid), [@aws-sdk/client-iot](https://github.com/aws/aws-sdk-js-v3/tree/HEAD/clients/client-iot), [@aws-sdk/client-iot-data-plane](https://github.com/aws/aws-sdk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
